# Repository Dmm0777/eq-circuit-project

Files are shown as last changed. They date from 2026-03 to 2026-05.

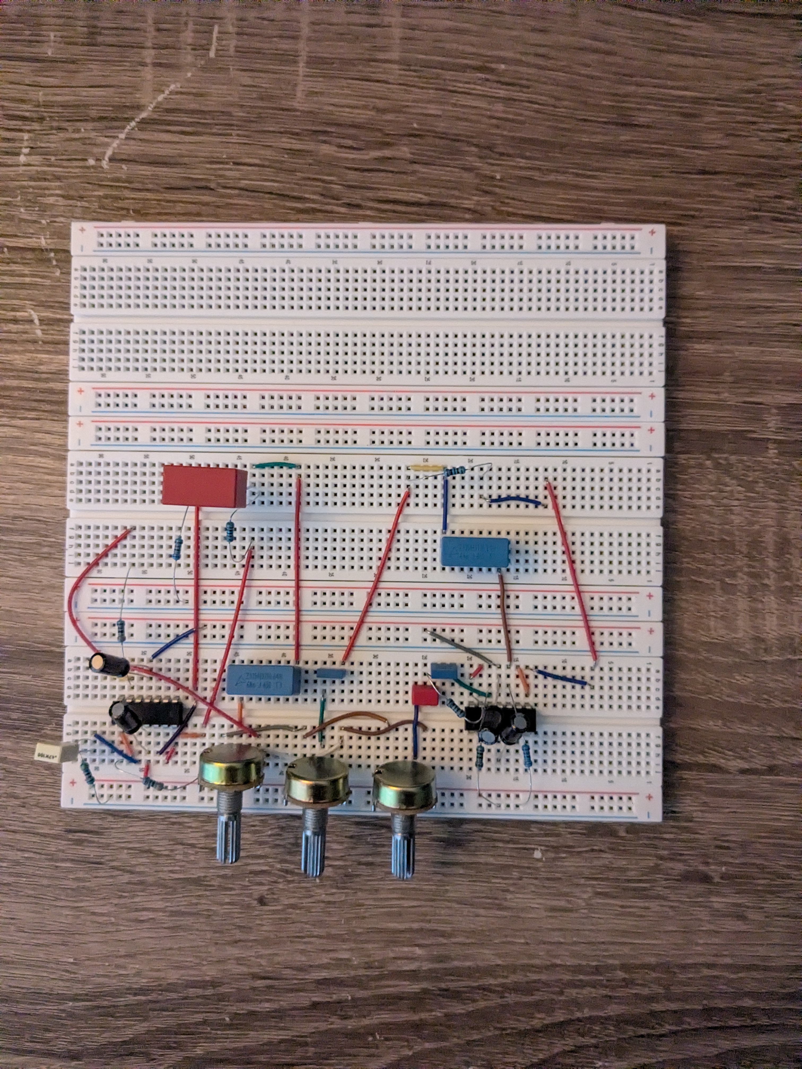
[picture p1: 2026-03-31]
hardware/photos/PXL_20260331_134624128.jpg

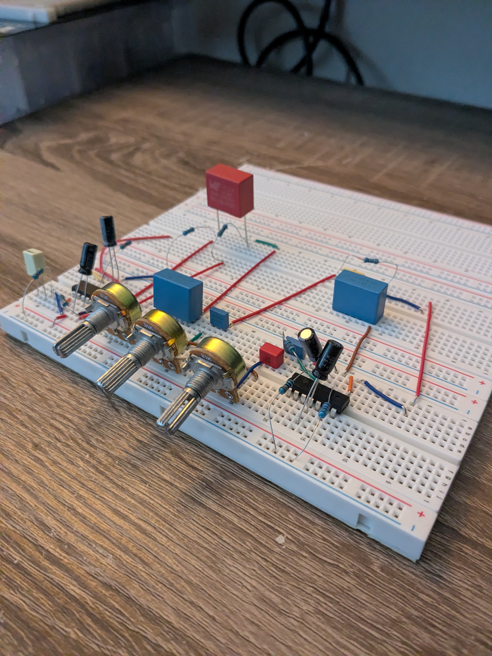
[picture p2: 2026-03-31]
hardware/photos/PXL_20260331_134629972.jpg

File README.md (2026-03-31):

This is a personal project designed, built and tested by me. The objective of the circuit is to help shape the signal of an electric guitar before amplification. 

The design implements 3 band pass filters in parallel with center frequencies of approximately 90, 900 and 9000 Hz for bass, middle and treble respectively.
It employs 3 operational amplifiers to boost or cut each band and is thus an active EQ circuit. 

This design includes an input buffer to ensure the signal sees a high input impedance, preventing loading. It also includes local decoupling capacitors between the power rails
and the op-amp power pins to ensure power stability. 

The project has already completed its design and simulation phases is currently in the prototype testing phase. More updates will be made to documentation soon.

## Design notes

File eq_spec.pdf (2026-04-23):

# 3-band Equalizer Specification & Requirements

## Overview

This circuit is designed to modify the frequency content of an electric guitar signal. To accomplish this, 3 band pass filters are implemented in parallel with center frequencies in the bass, middle and treble range. It is powered by a 15V dual supply.

## System Description

The system’s signal flow can be seen below.

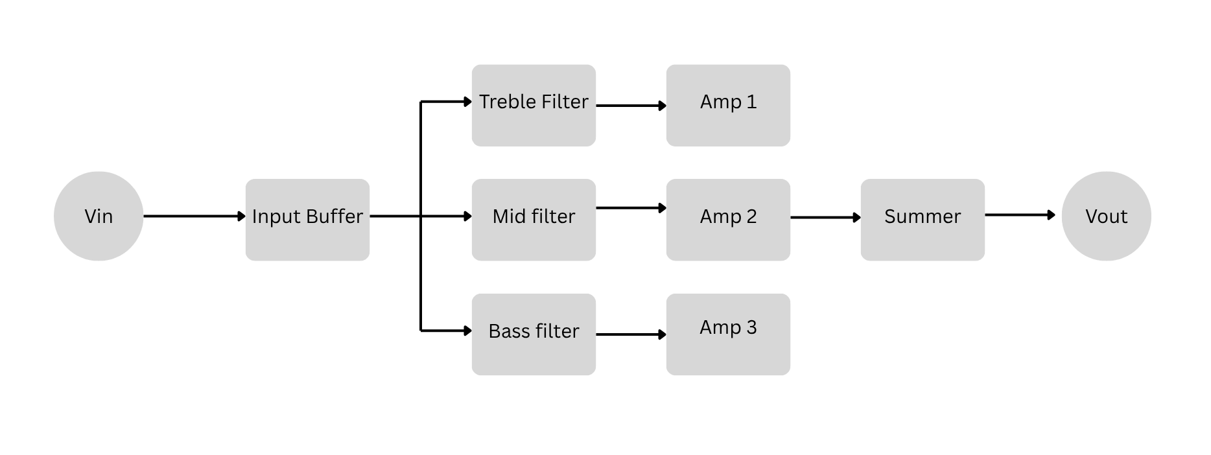
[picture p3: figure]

## System Performance Requirements

Req # | Requirement | Rationale | Parent Req | Child Req | Verification Method | Req met?
FUNC-001 | Circuit shall produce audible boost and cut in 3 frequency ranges | Purpose of circuit | N/A | FREQ-001, GAIN-001 | Demonstration | TBD
FUNC-002 | Frequency bands shall operate independently | Boosting/cutting one band should leave the other bands unaffected | N/A | FREQ-003 | Test | TBD
FUNC-003 | Frequency response shall be nearly flat at unity gain | The circuit should be transparent | N/A | FREQ-002 | Test | TBD
FUNC-004 | The circuit shall operate with minimal noise | Noise is distracting and diminishes the devices value as a tool | N/A | NOISE-001, NOISE-002 | Test | TBD
FUNC-005 | The circuit shall provide linear | Gain should be predictable and | N/A | GAIN-002 | Test | TBD

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

| t h e cir c uit s h all display a gain boost/cut of at least ±10dB at their center frequency | t o p r o d u c e a sig nific a n t, clearly audible effect
G AIN -0 0 2 | Cir c uit s h all produce line a r g ain b e t w e e n 2 0 a n d 5 0 0 m V | T his is a p p r o xim a t ely t h e d y n a mic r a n g e o f a g uit a r | F U N C -0 0 5 | N /A | Te s t | T B D
N OIS E -0 0 1 | Cir c uit s h all have a nois e flo o r o f le s s t h a n -6 0 d B ( < 1 m V r m s ) | T his v alu e is m u s t s m alle r t h a n t h e a v e r a g e g uit a r sig n al a m plit u d e | F U N C -0 0 4 | N /A | Te s t | T B D
N OIS E -0 0 2 | Cir c uit s h o uld h a v e a sig n al t o n ois e r a tio > 4 0 d B | T his v alu e giv e s a s t r o n g sig n al that overpower s n ois e | F U N C -0 0 4 | N /A | Te s t | T B D

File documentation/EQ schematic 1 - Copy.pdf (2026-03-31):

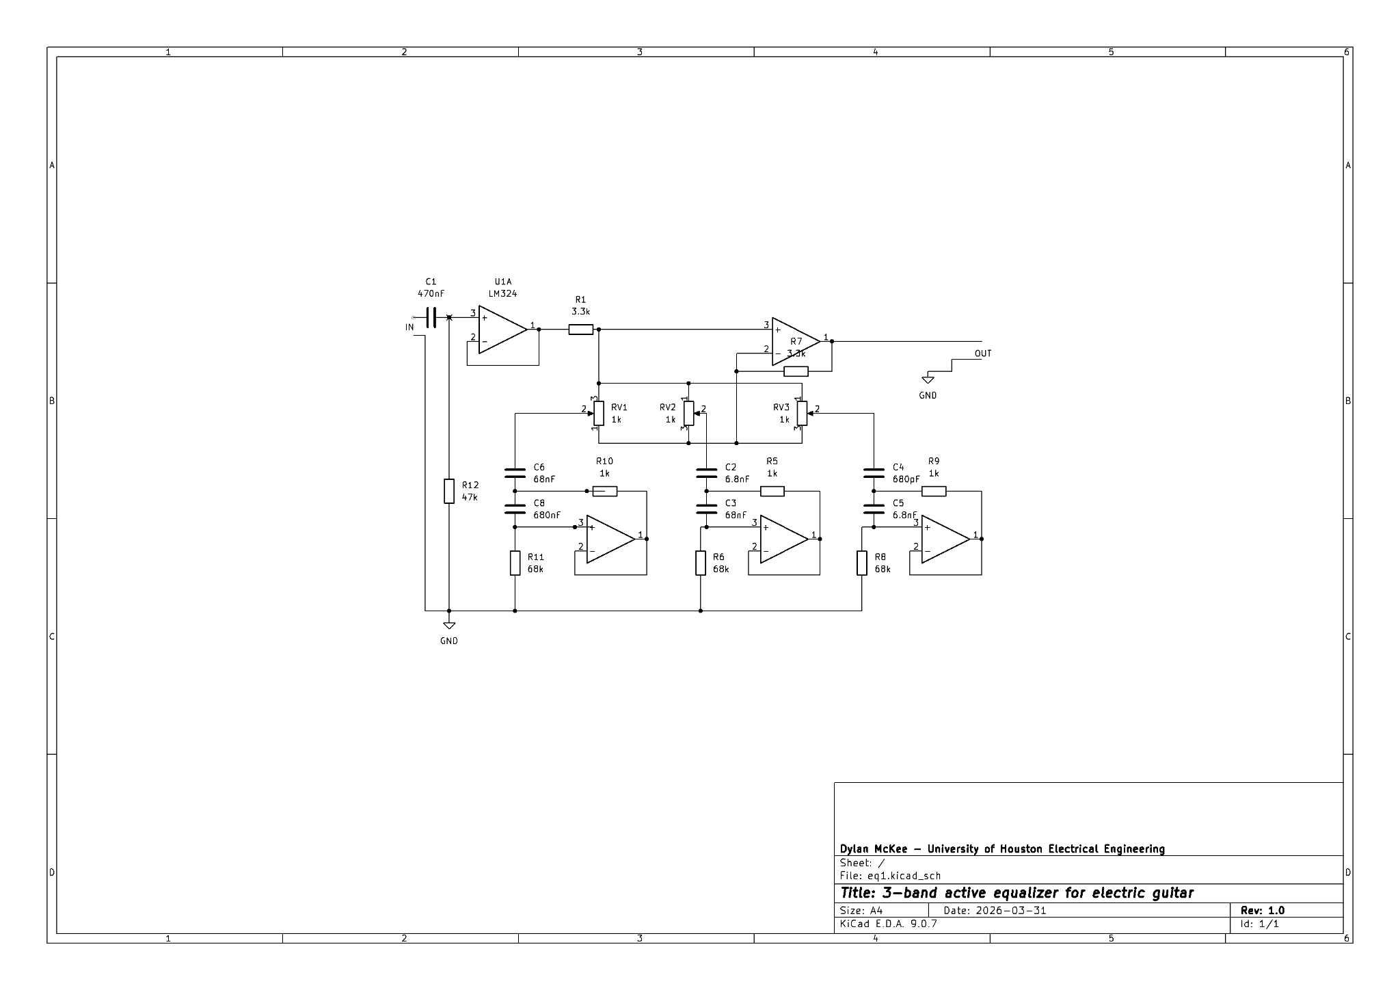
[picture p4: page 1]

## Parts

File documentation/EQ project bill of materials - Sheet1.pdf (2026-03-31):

BILL OF MATERIALS
AMP SECTION
Qty | Item | Notes
5 | U1A LM324
3 | Variable resistor 1k | With knobs
1 | 47k resistor
2 | 3.3k resistor
3 | 68k resistor | input resistor bass mid and treble
3 | 1k feedback resistor
1 | 470n cap | in front of buffer
1 | 680nF, 68nF | bass stage
1 | 68nF, 6.8nF | mid stage
1 | 6.8nF, 680pF | treble stage
10 | 10u cap | amp power caps
1 | large breadboard

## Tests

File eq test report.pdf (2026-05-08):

# Active 3-band Equalizer Test Report

## Author: Dylan McKee

## Organization: University of Houston ECE Department (ECE2202)

## Date: 05/08/2026

## Objective

The purpose of this test was to determine how well the system under test conformed to specifications. Additionally, it was intended to discover the viability or lack of viability of the prototype as currently designed for application in real music.

## System Under Test

The system under test is a 1st prototype of an active 3-band equalizer. It employs an input buffer in series with 3 active band-pass filters in series with a summing amplifier. A block diagram of the system can be seen in figure 1 below.

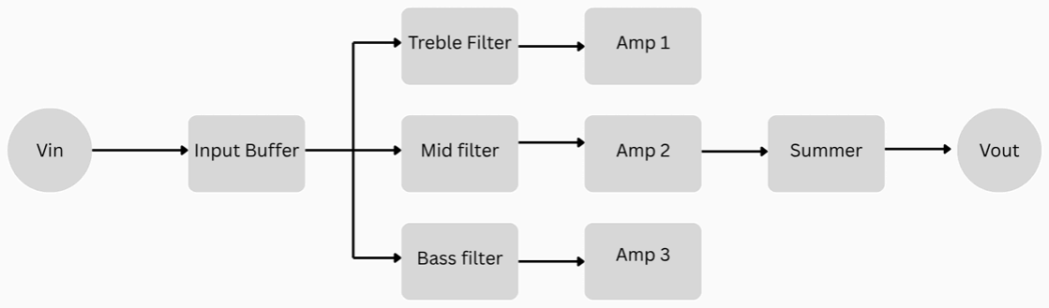
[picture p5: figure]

Figure 1. Block diagram of system under test

The system operates with Vin being a 100-500 [mVrms] sine wave. Under real conditions, the input signal is a composite of many frequencies with a periodic, heavy transient. It is powered by dual 15V rails with local decoupling employed for rail stability.

The system is tested to meet all requirements laid out in eq_spec.pdf. These requirements, while not summarized here, include requirements for gain linearity, frequency response, band independence and noise.

A schematic of the system can be seen below in figure 2.

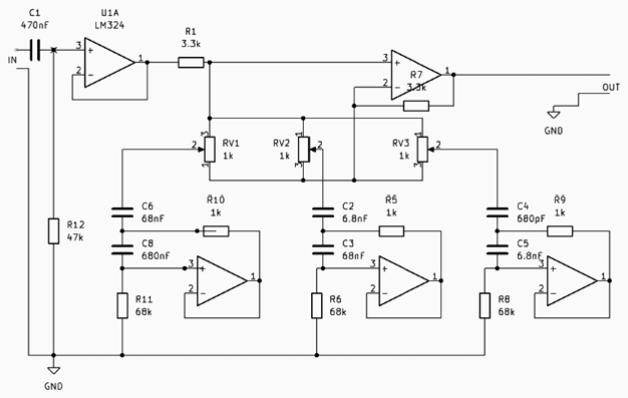
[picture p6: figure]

Figure 2. Schematic of system under test

## Test Procedure

The test procedure is set forth in a separate document, Test plan.pdf. The procedure was designed to test that the system meets each of the requirements laid out in the specification.

In general, the test procedure proceeds in 3 phases: 1) continuity testing, 2) controlled signal testing, 3) instrument signal testing. The test procedure was followed in the lab as outlined in the test plan.

## Results

The following results are laid out by requirement category.

### Frequency Response

A. Data

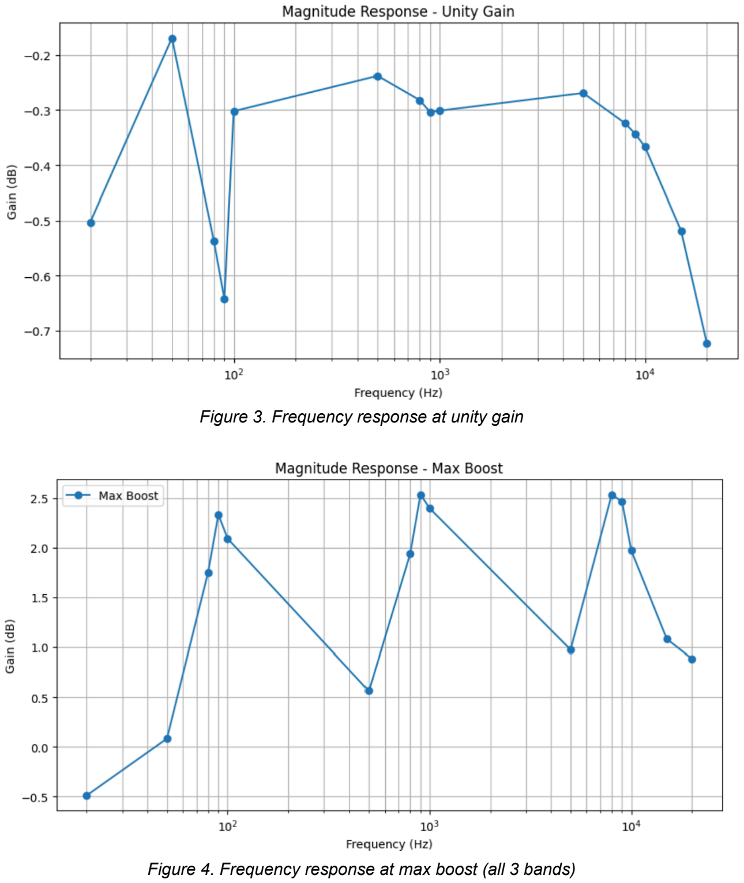
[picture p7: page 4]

Figure 3. Frequency response at unity gain

Figure 4. Frequency response at max boost (all 3 bands)

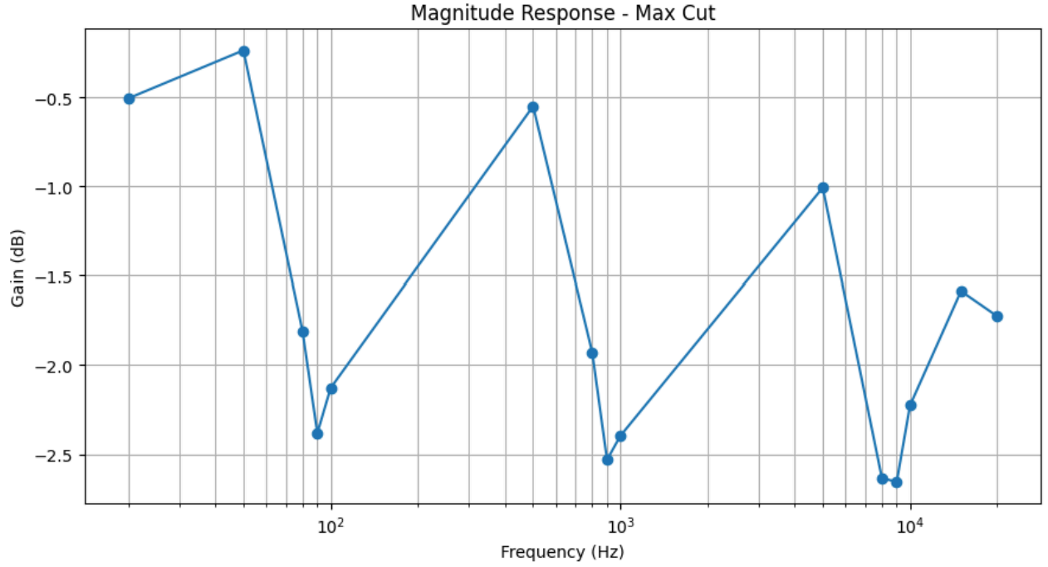
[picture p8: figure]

Figure 5. Frequency response at max cut (all 3 bands)

B. Relevant requirements
Requirement | Requirement Description | Pass/fail | Notes
FREQ-001 | Center frequencies at 90, 900 & 9000Hz ± 10% | PASS
FUNC-003 | Nearly flat response at unity | PASS
FREQ-002 | ± 1dB max at unity | PASS | Imprecise setting of pot knob
GAIN-001 | ± 10dB at f C | FAIL | See discussion

### Band Independence

Bands were all set to max cut then 1 was boosted at a time. The quantity ∆G was measured as the difference at that frequency between the baseline value and the boosted value. If operating properly, ∆G should be small for all bands besides the one being boosted at the time.

A. Data
| ∆G at 90Hz (dB) | ∆G at 900Hz (dB) | ∆G at 9000 Hz (dB)
Bass Boost | 4.707 | 0.725 | 0.747
Mid Boost | 0.007 | 4.33 | 0.730
Treble Boost | 0.001 | 0.009 | 3.647

Table 1. Band independence data, difference from baseline

B. Relevant Requirements
Requirement | Requirement Description | Pass/fail | Notes
FUNC-002 | Band independence (general) | PASS
FREQ-003 | ∆G < 1dB | PASS

### Gain linearity

The gain at the center frequency of all 3 bands was measured at various input amplitudes from 20 [mVrms] to 500 [mVrms]. It was observed that gain remains linear. It is observed that gain remains approximately constant in the amplitude range tested, which corresponds to the dynamic range of a guitar.

A. Data

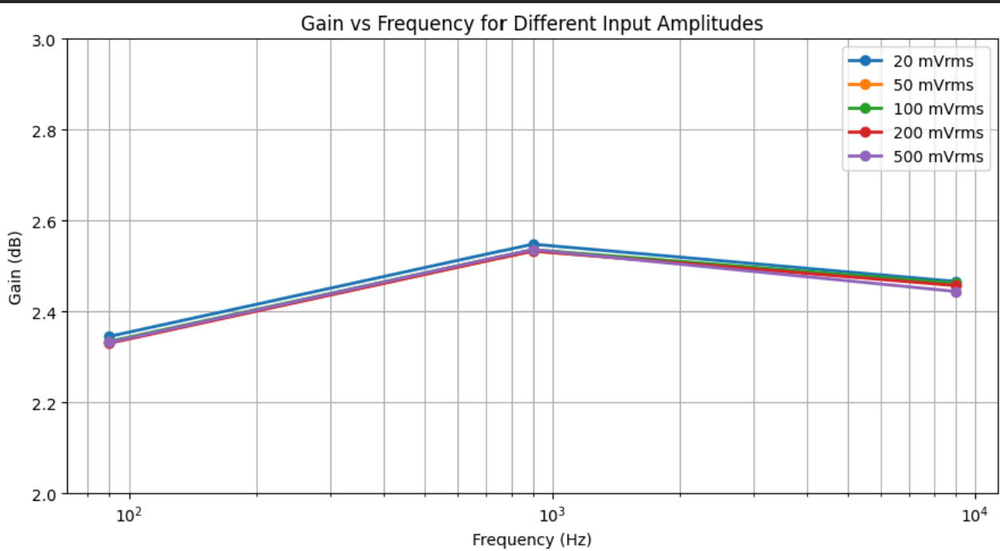
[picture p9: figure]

Figure 6: Gain linearity at 5 input amplitudes

B. Relevant requirements
Requirement | Requirement Description | Pass/fail | Notes
FUNC-005 | Linearity in operating range | PASS
GAIN-002 | Linear gain between 20 and 500 [mVrms] | PASS

### Instrument Signal Testing

A. Data

The device was observed to make a qualitative difference in frequency content in the 3 specified frequency ranges. More conclusive, quantitative testing can be conducted at a later date.

B. Relevant Requirements

Requirement | Requirement Description | Pass/fail | Notes
FUNC-001 | Audible boost/cut | PASS

## Discussion

The testing above demonstrates that all but 1 requirement are met by the device. This requirement, which specified a minimum ± 10dB gain at center frequencies, could be met in a second prototype after a simple redesign. Specifically, the feedback ratio of the summer should be increased approximately 5-fold to ensure gains reach 10dB.

The device accomplished its objective and, while not viable for immediate production, it proved to adhere well to requirements overall. Future iterations should address the low gain issue and conduct more comprehensive noise and instrument signal testing.

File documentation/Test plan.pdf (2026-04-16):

# Test Plan

## Overview

This document sets forth a test plan for a 3-band equalizer circuit for electric guitar. It will progress from validation and lab testing through real-world testing in 3 phases. The goal of this testing will be to ensure the reliable and predictable operation of the circuit, and to ensure it meets the design specification, which is summarized below.

## Specification Summary

The system shall be tested that it meets all functional, frequency, gain and noise requirements set forth in eq_spec.pdf. These requirements are quantified in that document, but a brief qualitative summary is included below.

1) The output signal should display a measurable and audible cut and boost in 3 frequency bands
2) The output signal should have minimal noise
3) The 3 filters should operate independently, such that the center frequency and max gain boost/cut in one band should not change when the other bands are adjusted
4) The circuit should be transparent when operating at unity gain in all 3 bands
5) Gain should remain linear in the operating interval

## Phase 1: Electrical Validation

### Goal

Verify the circuit is safe and powered correctly. Check for continuity and DC operating points.

### Tests

1.1. Wire checking and continuity
Verify all connections with circuit schematic. Check continuity between input and output.
1.2. Check power levels into op amp
Use a multimeter to ensure ± 12V is being delivered to the op-amp power pins.

1.3. DC Operating point
Apply a DC input signal and measure it at output. Ensure the circuit is transparent at unity gain. Sweep the potentiometer knobs one at a time and note the change in output if any.

## Phase 2: Controlled signal testing

### Goal

Use a function generator to produce a guitar-like signal. Quantify the circuit’s frequency response, band independence, gain and noise conditions under this input signal and ensure the device meets all relevant requirements.

### Tests

2.1 Frequency response
Measure output amplitude versus frequency. Run a frequency sweep from 20Hz - 20kHz with all EQ knobs simultaneously set to flat, max boost and max cut positions. Document the gain at each frequency under all 3 configurations.

2.2 Band independence
Boost and cut each frequency band individually. Check that the rest of the spectrum remains
relatively flat. Measure ∆G(f) = G | at the center frequency of the other 2 bands to
boost − G
flat
quantify band independence.

2.3 Gain and linearity
Measure the gain at center frequency of all 3 bands. Compare it to the theoretical gain values given the components in the circuit. Check to ensure these 3 gain values are within the allowed error defined by the spec.

Apply 5 different input amplitudes (20mV, 50mV, 100mV, 500mV, 1V) in the dynamic range of a guitar signal and measure the gain at each center frequency. Compare it to the expected gain and plot the trend.

2.4 Noise
Measure baseline noise by enforcing V through a 10k resistor (to mimic guitar pickup).
in = 0
Record V | and | . Use AC coupling. Also compute
noise, rms

V
| | noise, pp

SNR = 20log
10

(V
in

/V
noise

)
under the same gain conditions. Estimate the noise floor using FFT if available.

## Phase 3: Instrument signal testing

### Goal

Test the circuit under real operating conditions. Expose how it reacts to dynamic input signals.

### Tests

3.1 Noise
Connect the circuit to a computer through a transparent USB interface. Connect guitar to the circuit and turn volume to zero. Capture a 10s waveform. Do FFT and look at noise floor/PSD.

3.2 Single note testing
Set EQ bands to max cut, flat and max boost one at a time. Record a sample waveform with known fundamental frequency. Then sweep the potentiometers one at a time while sustaining a note and take notes on the character of the sound.

3.3 Real conditions
Play a simple song with the EQ on and record it. Note any issues with playability, user-interface or noise.

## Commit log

2026-03-31 KiCad schematic of prototype
    [eq1.kicad_sch]
2026-03-31 PDF version of EQ schematic
2026-03-31 KiCad Schematic of Circuit Prototype
    [eq1.kicad_sch]
2026-03-31 Bill of Materials
2026-03-31 Created schematics folder
2026-03-31 Upload bill of materials and project proposal
2026-03-31 Add prototype schematics
    [eq1 - Copy.kicad_sch]
2026-03-31 Added photos of prototype 1
